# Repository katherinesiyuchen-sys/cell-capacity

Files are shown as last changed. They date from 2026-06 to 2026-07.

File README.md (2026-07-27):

# Cell Capacity Tester
An Arduino-based constant-current discharge tester for 18650 lithium cells. It pulls a selected/controlled current out of a cell and 
integrates that current over time to compute the cell's true capacity in mAh, with live readout on an OLED and automatic thermal cutoff for safety.

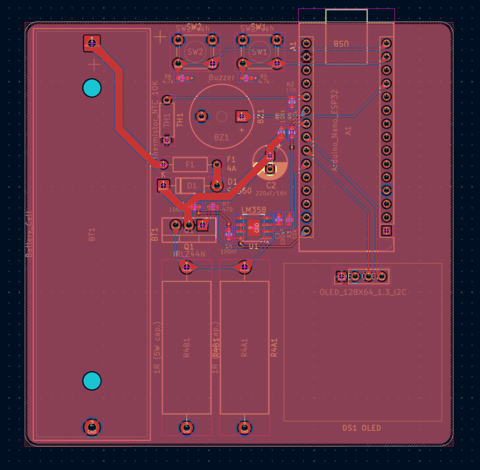
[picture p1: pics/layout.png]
layout

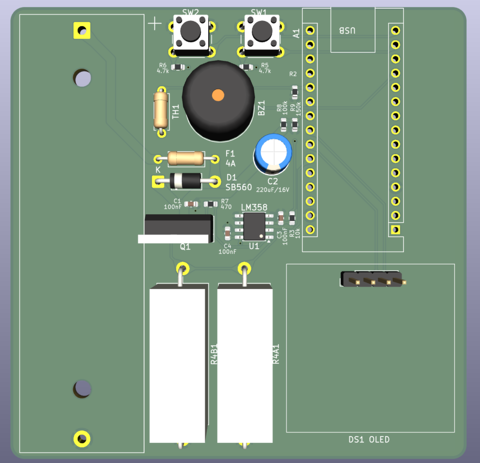
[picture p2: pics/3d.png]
3d-model


## How it works
The circuitry is a constant-current electronic load with an op-amp continuously adjusts a MOSFET's gate voltage to hold a selected discharge current steady 
regardless of the cell's falling voltage. By integrating that known current over time, the firmware accumulates total charge delivered, the cell's capacity, by multiplying the time and current.

## Circuit Overview
### Power system
BT1 (the 18650 cell) is the sole power source at ~3.6–4.2 V. Current flows from the positive terminal through **F1** (4 A resettable polyfuse) 
and **D1** (Schottky diode, low forward drop, blocks reverse insertion) onto the batt+ net. 
**C1 (100 nF)** and **C2 (220 µF)** in parallel stabilize batt+, where C2 absorbs voltage sags when the MOSFET draws heavy current, C1 filters high-frequency noise.

The Arduino is powered from USB (VUSB) +5V rail, and its 3V3 pin supplies the +3.3 V rail for the OLED.

### Constant-current discharge
- **Q1 (IRLZ44N)**: logic-level MOSFET in series with the load, acting as a variable resistor controlled by gate voltage. Fully on at 3.3–5 V, so it's directly Arduino-drivable.
- **R4A & R4B**: two 1 Ω / 10 W resistors in parallel (0.5 Ω total) as the sense/load resistors. All discharge current flows through them; voltage across them = I × 0.5 Ω.
- **U1A (LM358)**: op-amp in the feedback loop:
  - '–' input (pin 2): actual voltage across the load resistors (i.e. actual current)
  - '+' input (pin 3): filtered PWM from Arduino A2 (target current)
  - The op-amp drives the gate to null the difference: if actual current is too low the gate rises (MOSFET opens more); too high and it closes slightly.
- **R7 (470 Ω)** between op-amp output and gate damps high-frequency oscillation.
- **R3 / C3** form a low-pass RC filter (τ = 10k × 100 n = 1 ms) that smooths the A2 PWM into a steady DC target voltage.

### Current setting
**SW1 (D14)** and **SW2 (D15)** are pulled up to +5 V through R5/R6. Pressing a button pulls the pin to GND; the Arduino detects the falling edge and increases or decreases the A2 PWM duty cycle, 
which changes the target voltage at the op-amp and therefore the set current. SW1 is UP/START — it also begins the test.

### Temperature sensing
**TH1 (10k NTC thermistor)** forms a voltage divider with R2 (10k):
```
TEMP = 5 V × R2 / (R2 + TH1)
```
The Arduino reads TEMP on **A0**. As temperature rises, TH1's resistance drops and TEMP rises. Firmware uses this to cut off the test above a safe threshold. 
Mount TH1 as close to the battery holder as possible so it can be bent to contact the cell.

### OLED display (DS1)
128×64 I²C OLED powered from 3.3 V and displays voltage, current, temperature, and accumulated mAh live during the test.

### Buzzer
Driven directly by the Arduino, beeps on test start, end, and fault.

### Op-amp protection
The LM358 is a dual op-amp. U1A does the constant-current control; the unused sections are wired as unity-gain followers with negative feedback so their inputs aren't left floating 
(floating inputs can be driven to the rails by EMI, causing excess current draw and rail instability). C4 filters VCC into the op-amp.

## Bill of Materials
Full BOM: [Google Sheets](https://docs.google.com/spreadsheets/d/1DATSQ3IbzevVbkfX_8bRBYmYYDkdU8qtv9zlPYZS3Pw/edit?usp=sharing)

All components are sourced from **DigiKey** except the **OLED screen**, which is purchased from Amazon.

## License

Licensed under the [Apache License 2.0](LICENSE).

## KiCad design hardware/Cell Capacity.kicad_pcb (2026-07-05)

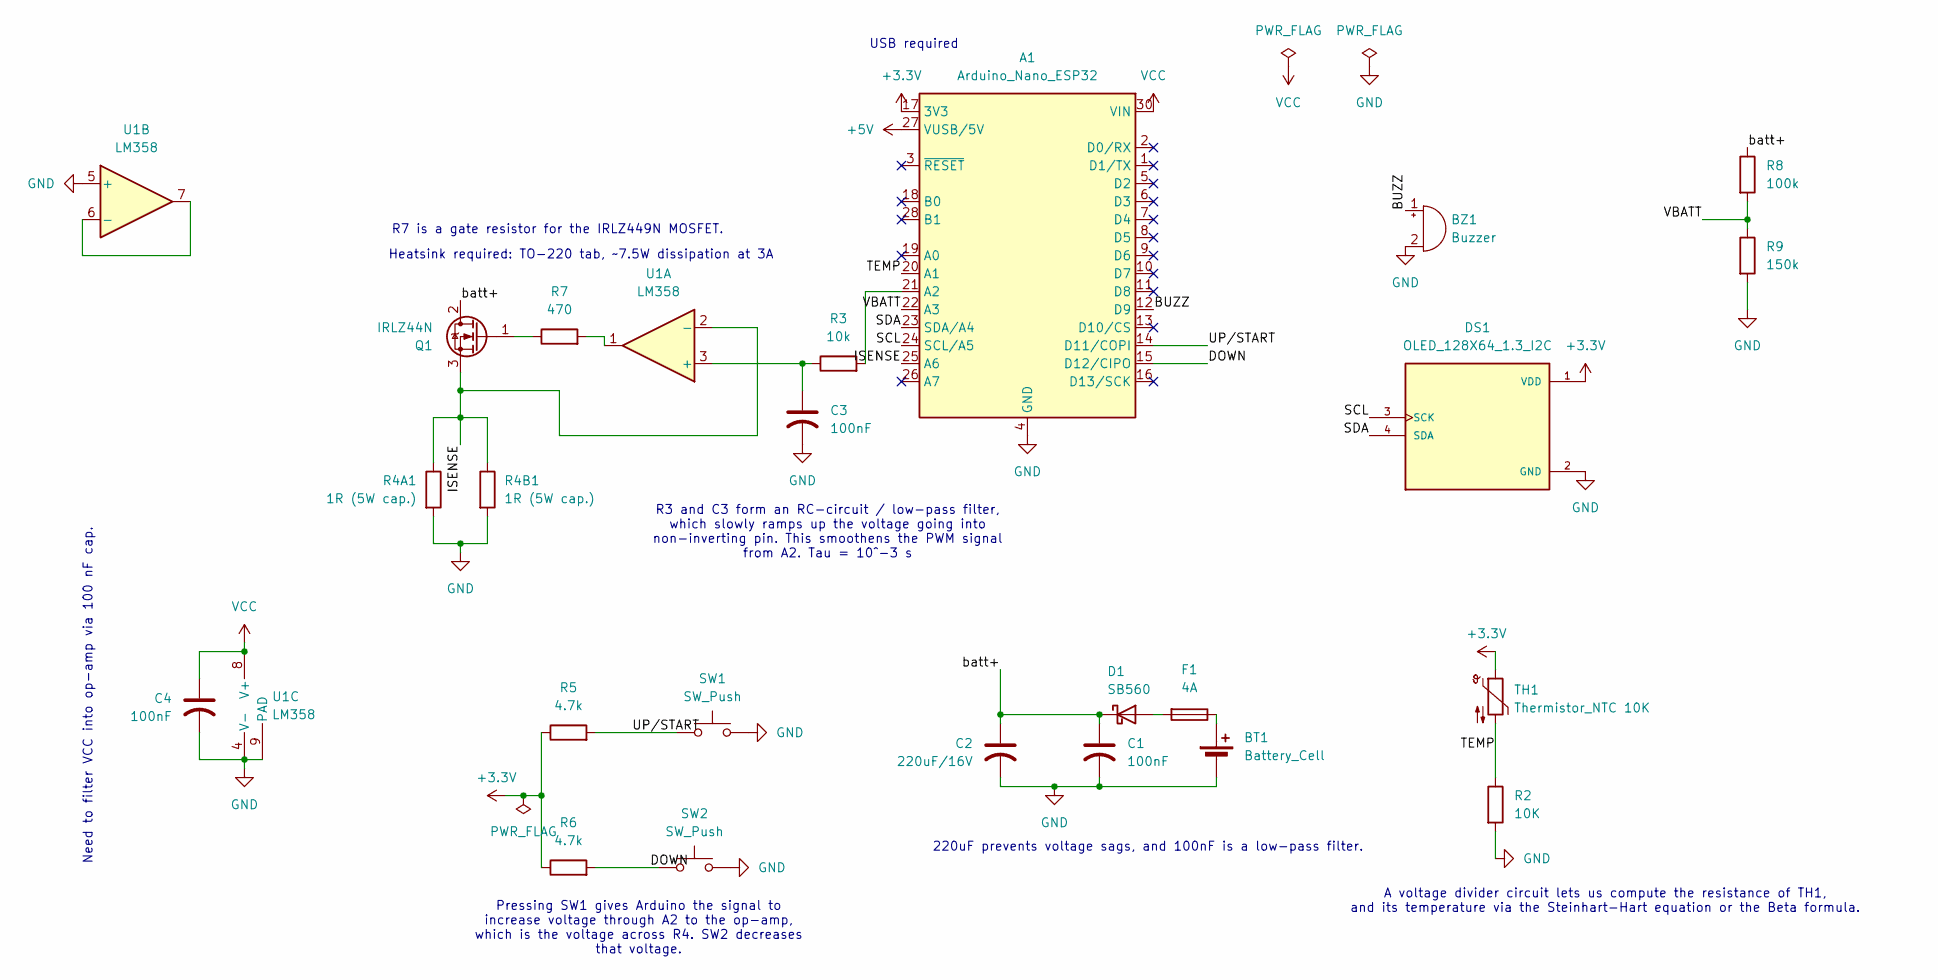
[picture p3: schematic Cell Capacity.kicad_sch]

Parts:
A1: Arduino_Nano_ESP32; Arduino_Nano
BT1: Battery_Cell; BatteryHolder_MPD_BK-18650-PC2
BZ1: Buzzer; Buzzer_12x9.5RM7.6
C1, C3, C4: 100nF; C_0603_1608Metric
C2: 220uF/16V; CP_Radial_D6.3mm_P2.50mm
D1: SB560; D_DO-41_SOD81_P10.16mm_Horizontal
DS1: OLED_128X64_1.3_I2C; PinHeader_1x04_P2.54mm_Vertical; PARTREV NA
F1: 4A; R_Axial_DIN0207_L6.3mm_D2.5mm_P10.16mm_Horizontal
Q1: IRLZ44N; TO-220-3_Vertical
R2: 10K; R_0603_1608Metric
R3: 10k; R_0603_1608Metric
R4A1, R4B1: 1R (5W cap.); R_Axial_Power_L25.0mm_W9.0mm_P30.48mm
R5, R6: 4.7k; R_0603_1608Metric
R7: 470; R_0603_1608Metric
R8: 100k; R_0603_1608Metric
R9: 150k; R_0603_1608Metric
SW1, SW2: SW_Push; SW_PUSH_6mm
TH1: Thermistor_NTC 10K; R_Axial_DIN0207_L6.3mm_D2.5mm_P7.62mm_Horizontal
U1: LM358; SOIC-8-1EP_3.9x4.9mm_P1.27mm_EP2.29x3mm

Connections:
+3.3V: A1.17 (3V3), DS1.1 (VDD), R5.1, R6.1, TH1.1; also elsewhere on the board
+5V: A1.27 (VUSB/5V)
/BUZZ: A1.12 (D9), BZ1.1 (+)
/DOWN: A1.15 (D12/CIPO), R6.2, SW2.1
/ISENSE: A1.25 (A6), Q1.3 (S), R4A1.1, R4B1.1, U1.2 (-)
/SCL: A1.24 (SCL/A5), DS1.3 (SCK); also elsewhere on the board
/SDA: A1.23 (SDA/A4), DS1.4 (SDA); also elsewhere on the board
/TEMP: A1.20 (A1), R2.1, TH1.2
/UP/START: A1.14 (D11/COPI), R5.2, SW1.1
/VBATT: A1.22 (A3), R8.2, R9.1
/batt+: C1.1, C2.1, D1.1 (K), Q1.2 (D), R8.1
GND: A1.4 (GND), A1.29 (GND), BT1.2 (-), BZ1.2 (-), C1.2, C2.2, C3.2, C4.2, DS1.2 (GND), R2.2, R4A1.2, R4B1.2, R9.2, SW1.2, SW2.2, U1.4 (V-), U1.5 (+), U1.9 (PAD); also elsewhere on the board
unnamed: A1.21 (A2), R3.2
unnamed: BT1.1 (+), F1.1
unnamed: D1.2 (A), F1.2
unnamed: Q1.1 (G), R7.1
unnamed: R7.2, U1.1
unnamed: C3.1, R3.1, U1.3 (+)
unnamed: U1.6 (-), U1.7
VCC: A1.30 (VIN), C4.1, U1.8 (V+)

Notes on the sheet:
Pressing SW1 gives Arduino the signal to increase voltage through A2 to the op-amp, which is the voltage across R4. SW2 decreases that voltage.
220uF prevents voltage sags, and 100nF is a low-pass filter.
R7 is a gate resistor for the IRLZ449N MOSFET.
R3 and C3 form an RC-circuit / low-pass filter, which slowly ramps up the voltage going into non-inverting pin. This smoothens the PWM signal from A2. Tau = 10^-3 s
USB required
Need to filter VCC into op-amp via 100 nF cap.
A voltage divider circuit lets us compute the resistance of TH1, and its temperature via the Steinhart-Hart equation or the Beta formula.
Heatsink required: TO-220 tab, ~7.5W dissipation at 3A

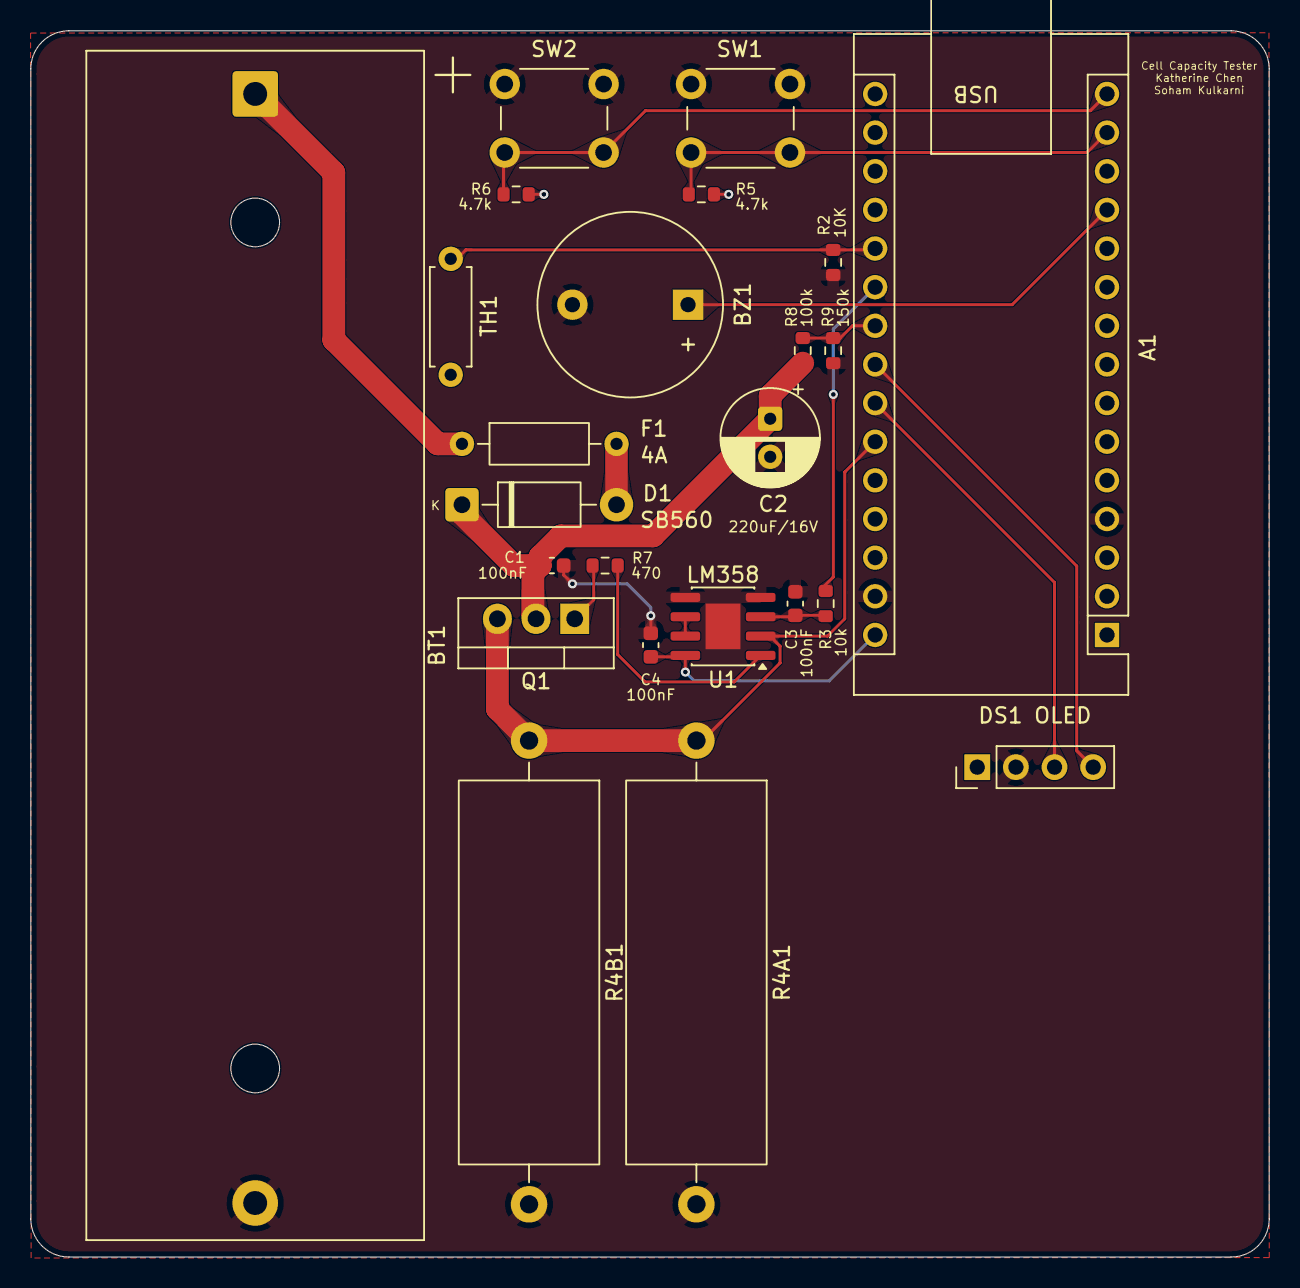
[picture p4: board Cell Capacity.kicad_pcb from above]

Board: 2 copper layers, 81.4 x 80.6 mm, 24 parts (0 on the bottom side), 19 nets.

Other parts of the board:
DS1 OLED: OLED_128X64_1.3_I2C; PinHeader_1x04_P2.54mm_Vertical

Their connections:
+3.3V: DS1 OLED.1 (VDD); also elsewhere on the board
/SCL: DS1 OLED.3 (SCK); also elsewhere on the board
/SDA: DS1 OLED.4 (SDA); also elsewhere on the board
GND: DS1 OLED.2 (GND); also elsewhere on the board

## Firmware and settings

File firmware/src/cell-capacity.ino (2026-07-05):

/*
 * Cell Capacity Tester — firmware
 * ---------------------------------
 * Constant-current 18650 discharge tester. An LM358 op-amp holds the discharge
 * current constant by driving a MOSFET gate; this firmware sets the target
 * current (via a filtered PWM "DAC"), measures the actual current, integrates
 * it over time to compute capacity (mAh), watches temperature and cell voltage
 * for safety cutoffs, and shows everything on a 128x64 I2C OLED.
 *
 * Libraries required (install via Library Manager):
 *   - Adafruit SSD1306
 *   - Adafruit GFX
 */

#include <Wire.h>
#include <Adafruit_GFX.h>
#include <Adafruit_SSD1306.h>

// ─── pin configuration ───────────────────────────
#define PIN_TEMP        A0   // NTC thermistor divider
#define PIN_VBAT        A1   // cell voltage sense (batt+)
#define PIN_ISENSE      A3   // voltage across load resistors (actual current)
#define PIN_CURRENT_PWM 3    // filtered PWM -> op-amp + input (target current)
#define PIN_BTN_UP      4    // SW1: UP / START (external pull-up per R5)
#define PIN_BTN_DOWN    5    // SW2: DOWN (external pull-up per R6)
#define PIN_BUZZER      6    // piezo buzzer

// ─── constants ─────────────────────────────────────────────────────
const float VREF = 5.0;    // ADC reference (5V rail)
const float ADC_MAX = 1023.0; // 10-bit ADC
const float R_SENSE = 0.5;    // R4A || R4B = 1 || 1 = 0.5 ohm
const float VBAT_DIV = 1.0;   // set to (R_top+R_bot)/R_bot if VBAT is divided; 1.0 = direct
const uint8_t ADC_SAMPLES = 8;   // averaged reads per measurement for noise reduction

// Thermistor (NTC): 10k @ 25C, series/divider with R2 = 10k.
// Divider: TEMP = VREF * R2 / (R2 + Rntc)  (NTC to VREF, R2 to GND)
const float NTC_R0 = 10000.0; // resistance at 25C
const float NTC_T0 = 298.15;  // 25C in Kelvin
const float NTC_BETA = 3950.0;  // beta coefficient — check your part
const float R_FIXED = 10000.0; // R2

// ─── trip limits ───────────────────────────────────────────────────
const float V_CUTOFF = 2.50;   // stop discharge at this cell voltage 
const float TEMP_MAX_C = 60.0;   // fault cutoff temperature
const float I_MIN_MA = 100.0;  // min selectable current
const float I_MAX_MA = 2000.0; // max selectable current
const float I_STEP_MA = 100.0;  // adjustment step
const float V_NO_CELL = 1.00;   // below this at start = no cell inserted
const float I_FAULT_MA = 2500.0; // hard over-current fault
const unsigned long MAX_TEST_MS = 24UL * 3600000UL; // 24h watchdog timeout

// ─── state ──────────────────────────────────────────────────────────────────
enum State { IDLE, RUNNING, DONE, FAULT };
unsigned long lastDisplayMs = 0;
unsigned long lastLogMs = 0;
bool displayOk = false;

struct Readings { float vCell; float current_mA; float tempC; };
Readings sensors = {0, 0, 25.0};
State state = IDLE;

float targetCurrent_mA = 500.0;   // selected setpoint
float capacity_mAh = 0.0;     // accumulated capacity
unsigned long lastIntegrateMs = 0;
unsigned long testStartMs = 0;
const char *faultReason = "";

// Button debounce
struct Button {
  uint8_t pin;
  bool lastRaw;
  bool stable;
  unsigned long lastChangeMs;
  unsigned long pressedAtMs;
  bool longFired;
};

Button btnUp   = {PIN_BTN_UP,   HIGH, HIGH, 0, 0, false};
Button btnDown = {PIN_BTN_DOWN, HIGH, HIGH, 0, 0, false};
const unsigned long DEBOUNCE_MS  = 30;
const unsigned long LONGPRESS_MS = 1000;
const unsigned long DISPLAY_MS = 200;   // OLED refresh interval
const unsigned long LOG_MS = 1000;  // serial CSV log interval

Adafruit_SSD1306 display(128, 64, &Wire, -1);

void setup() {
  pinMode(PIN_CURRENT_PWM, OUTPUT);
  pinMode(PIN_BUZZER, OUTPUT);
  pinMode(PIN_BTN_UP, INPUT);    // external pull-ups (R5/R6). Use INPUT_PULLUP if none.
  pinMode(PIN_BTN_DOWN, INPUT);
  setDischarge(0);     // ensure load is off at boot
  #if defined(__AVR__) && (PIN_CURRENT_PWM == 3 || PIN_CURRENT_PWM == 11)
  TCCR2B = (TCCR2B & 0b11111000) | 0x01;   // ~490 Hz -> ~31 kHz, smoother DAC
  #endif

  Serial.begin(115200);

  Serial.println(F("# time_s,V,I_mA,T_C,mAh"));
  displayOk = display.begin(SSD1306_SWITCHCAPVCC, 0x3C);
  if (!displayOk) Serial.println(F("# WARNING: OLED init failed"));

  display.clearDisplay();
  display.setTextColor(SSD1306_WHITE);
  display.display();
}

void loop() {
  pollButtons();
  switch (state) {
    case IDLE:    handleIdle();    break;
    case RUNNING: handleRunning(); break;
    case DONE:    handleDone();    break;
    case FAULT:   handleFault();   break;
  }
  sensors = readSensors();
  updateDisplay();
}

void handleIdle() {
  setDischarge(0);
  // UP short = increase current, DOWN short = decrease current, UP long = START
  if (btnUp.longFired) {
    btnUp.longFired = false;
    startTest();
  }
}

void handleRunning() {
  if (sensors.tempC >= TEMP_MAX_C) { 
    faultReason = "OVERTEMP";    
    enterFault(); 
    return; 
  }
  if (sensors.current_mA >= I_FAULT_MA) { 
    faultReason = "OVERCURRENT"; 
    enterFault(); 
    return; 
  }
  if (millis() - testStartMs > MAX_TEST_MS) { 
    faultReason = "TIMEOUT";     
    enterFault(); return; 
  }
  if (sensors.vCell <= V_CUTOFF) { 
    finishTest(); 
    return; 
  }

  // integrate charge: mAh += mA * (dt in hours)
  unsigned long now = millis();
  float dtHours = (now - lastIntegrateMs) / 3600000.0;
  lastIntegrateMs = now;
  capacity_mAh += i * dtHours;
}

void handleDone()  { setDischarge(0); }
void handleFault() { setDischarge(0); }

// ─── test control ───────────────────────────────────────────────────────────
void startTest() {
  if (sensors.vCell < V_NO_CELL) { 
    faultReason = "NO CELL"; 
    enterFault(); 
    return; 
  }
  capacity_mAh = 0.0;
  applyTargetCurrent();
  beep(2, 80);
  testStartMs = millis();
  lastIntegrateMs = testStartMs;
  lastLogMs = testStartMs;
  state = RUNNING;
}

void finishTest() {
  setDischarge(0);
  state = DONE;
  beep(3, 150);  // three beeps: complete
}

void enterFault() {
  setDischarge(0);
  state = FAULT;
  beep(5, 300);  // long fault pattern
}

// ─── current control ────────────────────────────────────────────────────────
// Target current is set by the voltage on the op-amp + input:
//   V_target = I_target(A) * R_SENSE
// The filtered PWM produces  V = (duty/255) * VREF, so:
//   duty = V_target / VREF * 255
void applyTargetCurrent() {
  float vTarget = (targetCurrent_mA / 1000.0) * R_SENSE;
  int duty = (int)((vTarget / VREF) * 255.0 + 0.5);
  duty = constrain(duty, 0, 255);
  analogWrite(PIN_CURRENT_PWM, duty);
}

void setDischarge(int duty) {
  analogWrite(PIN_CURRENT_PWM, constrain(duty, 0, 255));
}

// ─── measurement ────────────────────────────────────────────────────────────
float readVolts(uint8_t pin) {
  uint32_t acc = 0;
  for (uint8_t i = 0; i < ADC_SAMPLES; i++) {
    acc += analogRead(pin);
  }
  return (acc / (float)ADC_SAMPLES) * (VREF / ADC_MAX);
}

Readings readSensors() {
  Readings r;
  r.vCell = readVolts(PIN_VBAT) * VBAT_DIV;
  r.current_mA = (readVolts(PIN_ISENSE) / R_SENSE) * 1000.0;
  r.tempC = tempFromVolts(readVolts(PIN_TEMP));
  return r;
}

float tempFromVolts(float vNode) {
  if (vNode <= 0.001 || vNode >= VREF - 0.001) {
    return NAN;  // open/short thermistor
  }
  float rNtc = R_FIXED * (VREF / vNode - 1.0);
  float tK = 1.0 / (1.0 / NTC_T0 + (1.0 / NTC_BETA) * log(rNtc / NTC_R0));
  return tK - 273.15;
}

void logCsv() {
  unsigned long now = millis();
  if (now - lastLogMs < LOG_MS) {
    return;
  }
  lastLogMs = now;
  Serial.print((now - testStartMs) / 1000.0, 1); Serial.print(',');
  Serial.print(sensors.vCell, 3); Serial.print(',');
  Serial.print(sensors.current_mA, 1); Serial.print(',');
  Serial.print(sensors.tempC, 1); Serial.print(',');
  Serial.println(capacity_mAh, 2);
}
// ─── display ────────────────────────────────────────────────────────────────
void updateDisplay() {
  display.clearDisplay();
  display.setTextSize(1);
  display.setCursor(0, 0);

  switch (state) {
    case IDLE:
      display.println(F("READY"));
      display.print(F("Set: "));
      display.print(targetCurrent_mA, 0);
      display.println(F(" mA"));
      display.println();
      display.println(F("UP/DOWN: set current"));
      display.println(F("hold UP: start"));
      break;

    case RUNNING:
      display.println(F("DISCHARGING"));
      printLine(F("V:  "), readVolts(), F(" V"));
      printLine(F("I:  "), readSensors(), F(" mA"));
      printLine(F("T:  "), tempFromVolts(), F(" C"));
      printLine(F("Cap:"), capacity_mAh, F(" mAh"));
      break;

    case DONE:
      display.println(F("TEST COMPLETE"));
      printLine(F("Cap:"), capacity_mAh, F(" mAh"));
      printLine(F("V:  "), tempFromVolts(), F(" V"));
      break;

    case FAULT:
      display.println(F("!! FAULT !!"));
      display.println(faultReason);
      printLine(F("Cap:"), capacity_mAh, F(" mAh"));
      break;
  }
  display.display();
}

void serviceDisplay() {
  unsigned long now = millis();
  if (now - lastDisplayMs < DISPLAY_MS) return;
  lastDisplayMs = now;
  updateDisplay();
}

void printLine(const __FlashStringHelper *label, float value, const __FlashStringHelper *unit) {
  display.print(label);
  display.print(value, 1);
  display.println(unit);
}

// ─── buttons ────────────────────────────────────────────────────────────────
void pollButtons() {
  updateButton(btnUp,   onUpShort,   onUpLong);
  updateButton(btnDown, onDownShort, NULL);
}

void updateButton(Button &b, void (*onShort)(), void (*onLong)()) {
  bool raw = digitalRead(b.pin);
  unsigned long now = millis();

  if (raw != b.lastRaw) { 
    b.lastChangeMs = now; 
    b.lastRaw = raw; 
  }
  if ((now - b.lastChangeMs) > DEBOUNCE_MS && raw != b.stable) {
    b.stable = raw;
    if (b.stable == LOW) { // pressed (active low)
      b.pressedAtMs = now;
      b.longFired = false;
    } else {  // released
      if (!b.longFired && onShort) onShort();
    }
  }

  // long-press fires while still held
  if (b.stable == LOW && !b.longFired && onLong &&
      (now - b.pressedAtMs) > LONGPRESS_MS) {
    b.longFired = true;
    onLong();
  }
}

void onUpShort() {
  if (state == IDLE) {
    targetCurrent_mA = min(targetCurrent_mA + I_STEP_MA, I_MAX_MA);
  } else if (state == DONE || state == FAULT) {
    state = IDLE;         // acknowledge -> back to ready
  }
}

void onUpLong() {
  if (state == IDLE) startTest();     // hold UP to start
}

void onDownShort() {
  if (state == IDLE) {
    targetCurrent_mA = max(targetCurrent_mA - I_STEP_MA, I_MIN_MA);
  } else if (state == RUNNING) {
    finishTest();          // DOWN aborts a running test
  } else {
    state = IDLE;
  }
}

// ─── buzzer ─────────────────────────────────────────────────────────────────
void beep(int count, int ms) {
  for (int i = 0; i < count; i++) {
    digitalWrite(PIN_BUZZER, HIGH);
    delay(ms);
    digitalWrite(PIN_BUZZER, LOW);
    if (i < count - 1) delay(ms);
  }
}

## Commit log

2026-06-16 layout iter2
    [Cell Capacity.kicad_pcb]
2026-06-17 misc fix
    [Cell Capacity.kicad_pcb]
2026-07-04 Add README
    Added sourcing information for components in BOM.
2026-07-05 update measurement, setup, and display
    [Cell Capacity.kicad_pcb, Cell Capacity.kicad_sch]
